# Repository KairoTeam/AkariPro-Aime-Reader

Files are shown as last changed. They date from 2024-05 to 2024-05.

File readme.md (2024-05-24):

# Akari Pro
使用 RP2040 + PN532 制作的适用于SEGA/KONAMI Aime 兼容读卡器，KairoTech闲鱼出售商品（现已经被Akari II替代）  

由于剩余大量物料，加群645758744可以付邮送一些~


- 支持卡片类型: [FeliCa](https://zh.wikipedia.org/wiki/FeliCa)（Amusement IC、Suica、八达通等）和 [MIFARE](https://zh.wikipedia.org/wiki/MIFARE)（Aime，Banapassport）
- 固件基于Mahuyo大佬的[Arduino-Aime-Reader](https://github.com/Sucareto/Arduino-Aime-Reader/blob/main/README.md)，十分感谢大佬Orz

固件相关信息和使用方法请查看Mahuyo大佬的[Arduino-Aime-Reader](https://github.com/Sucareto/Arduino-Aime-Reader/blob/main/README.md)，本项目仅修改了引脚定义以及适配RP2040

- 如果读卡器没有正常工作且游戏有使用 amdaemon 的，可以参考 config_common.json 内 aime > unit > port 确认端口号

### 使用教程
1. 焊接好PCB（废话）
2. 如果是新的RP2040可以直接插入，否则短接PCB上的flash的左边第一脚和最后一脚的同时接入USB线缆，在打开的新磁盘内放入AkariPro_1.00_202312111729.uf2
3. 测试完成后将PCB放入3D外壳并装好螺丝
4. 定位好磁铁后使用胶水将磁铁粘在顶板上（需要注意的是，部分胶水会对UV印刷层产生影响，我们使用的是百得的胶水）
5. 等待胶水硬化之后就可以测试一下能否正常安装，磁铁的定位请十分注意
6. 大功告成~

### 物料清单
- PCB元件: 在Repo的PCB文件夹内，但需要注意RP2040很挑Flash，淘宝里不到1RMB的基本无法使用，推荐买正规的Flash
- PCB制造 & 3D打印: 推荐嘉立创，3D请注意使用光固化
- 亚克力面板: 淘宝随便找，一般差距不会太大，使用UV印刷
- 螺母: 淘宝固万基旗舰店的[镀镍十字扁平头螺丝](https://m.tb.cn/h.g1rzLvyOX09U4BH?tk=sZ6CWHJcB1r)（自行购买请一定注意能否被磁铁吸住）
- 螺丝: 淘宝固万基旗舰店的[内六角夹板螺母](https://m.tb.cn/h.g1apAKJ12Nif9Q6?tk=VZhZWHJ1jPt MF7997)
- 磁铁: 淘宝鑫涌泉磁业[小圆形磁铁](https://m.tb.cn/h.gYnSHoJE2Vr6VK5?tk=gqvIWHJ1VeJ)

### 图片
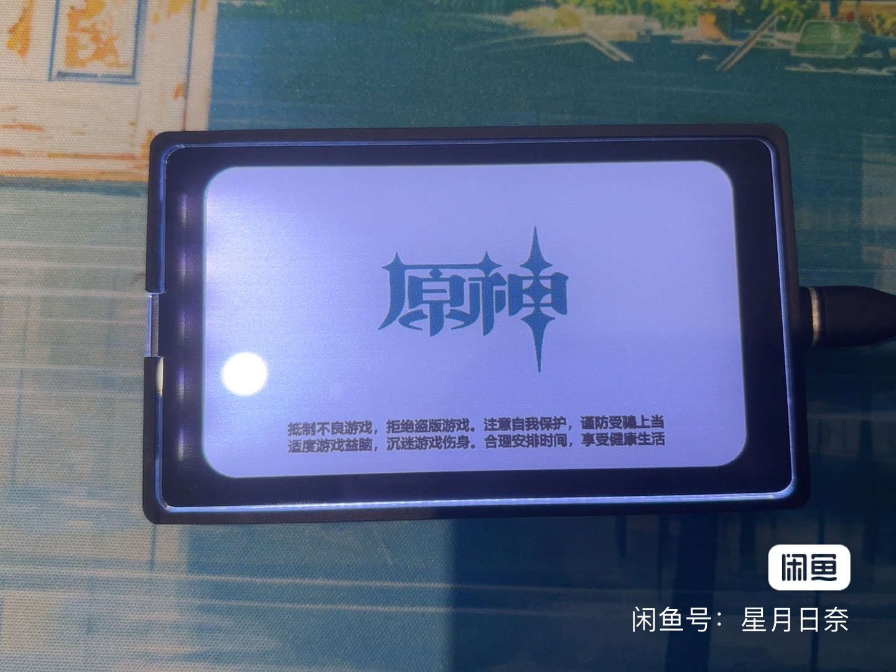
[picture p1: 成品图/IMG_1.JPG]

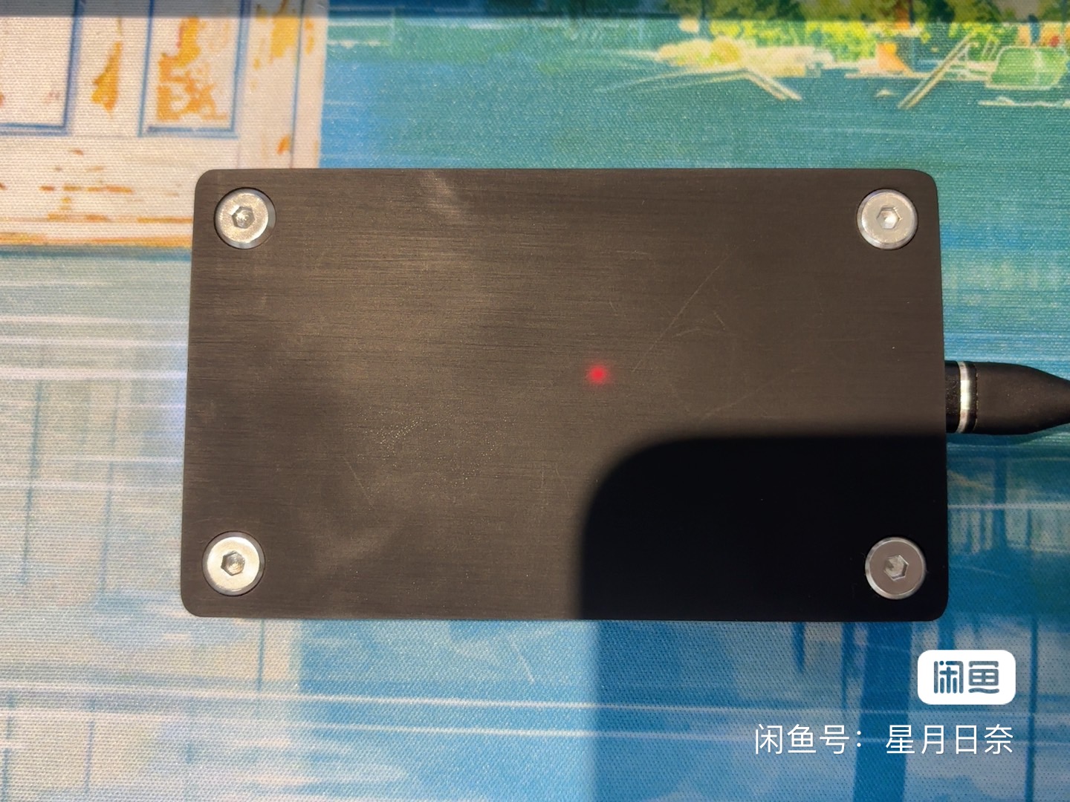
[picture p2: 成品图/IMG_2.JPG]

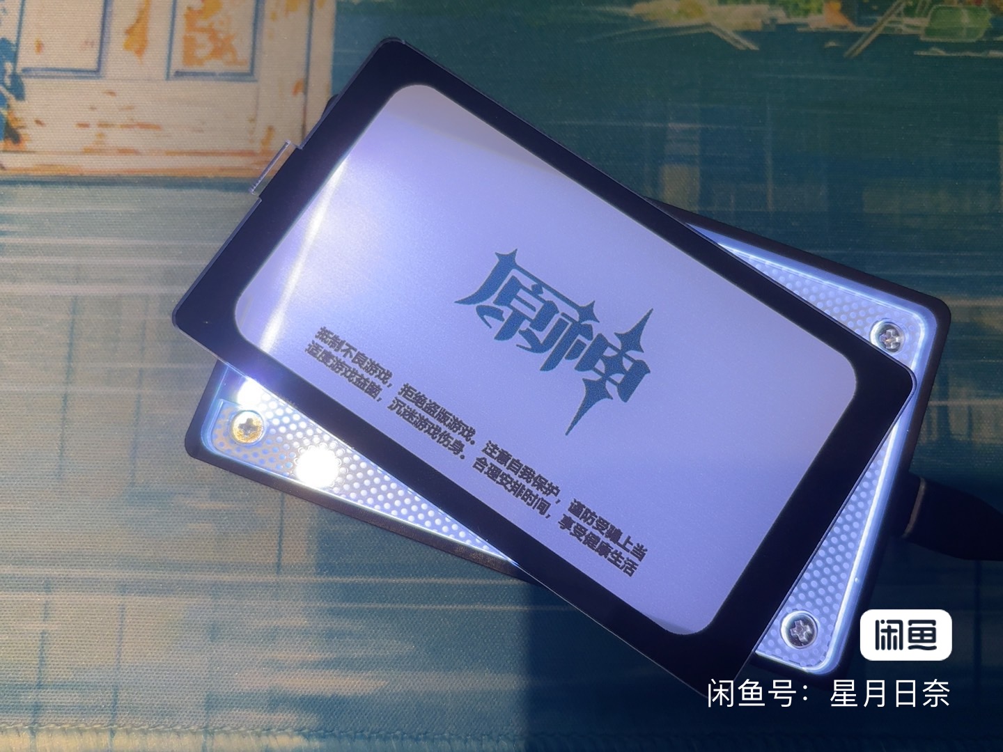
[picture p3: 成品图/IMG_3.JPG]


### 引用库：
- 固件: [Arduino-Aime-Reader](https://github.com/Sucareto/Arduino-Aime-Reader/blob/main/README.md)
- 驱动 WS2812B: [FastLED](https://github.com/FastLED/FastLED)
- 驱动 PN532: [PN532](https://github.com/elechouse/PN532) 或 [Aime_Reader_PN532](https://github.com/Sucareto/Aime_Reader_PN532)
- 读取 FeliCa 参考: [PN532を使ってArduinoでFeliCa学生証を読む方法](https://qiita.com/gpioblink/items/91597a5275862f7ffb3c)
- 读取 FeliCa 数据的程序: [NFC TagInfo](https://play.google.com/store/apps/details?id=at.mroland.android.apps.nfctaginfo)，[NFC TagInfo by NXP](https://play.google.com/store/apps/details?id=com.nxp.taginfolite)
- MIFARE 读写卡，数据分析: [MifareClassicTool](https://github.com/ikarus23/MifareClassicTool)，[MifareOneTool](https://github.com/xcicode/MifareOneTool)

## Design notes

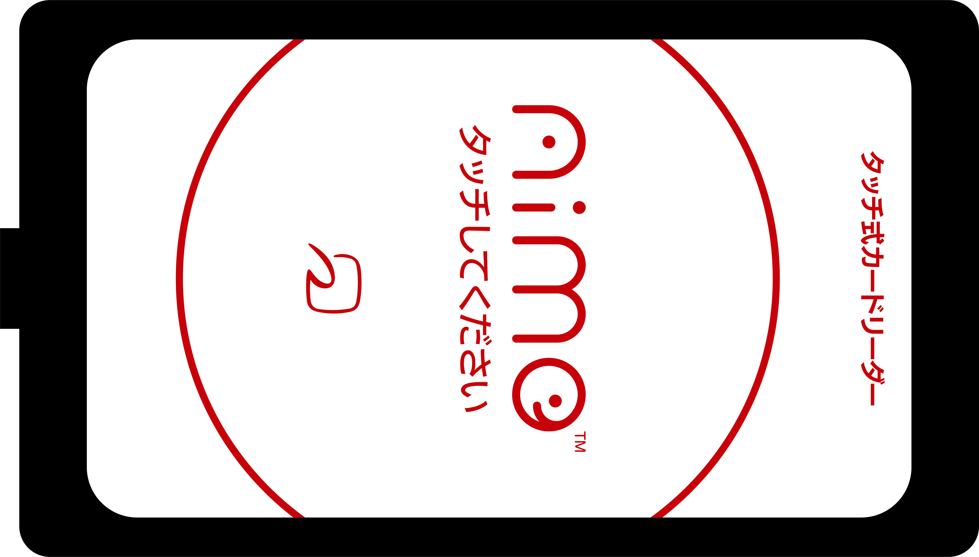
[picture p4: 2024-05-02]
面板/AIME_竖.png

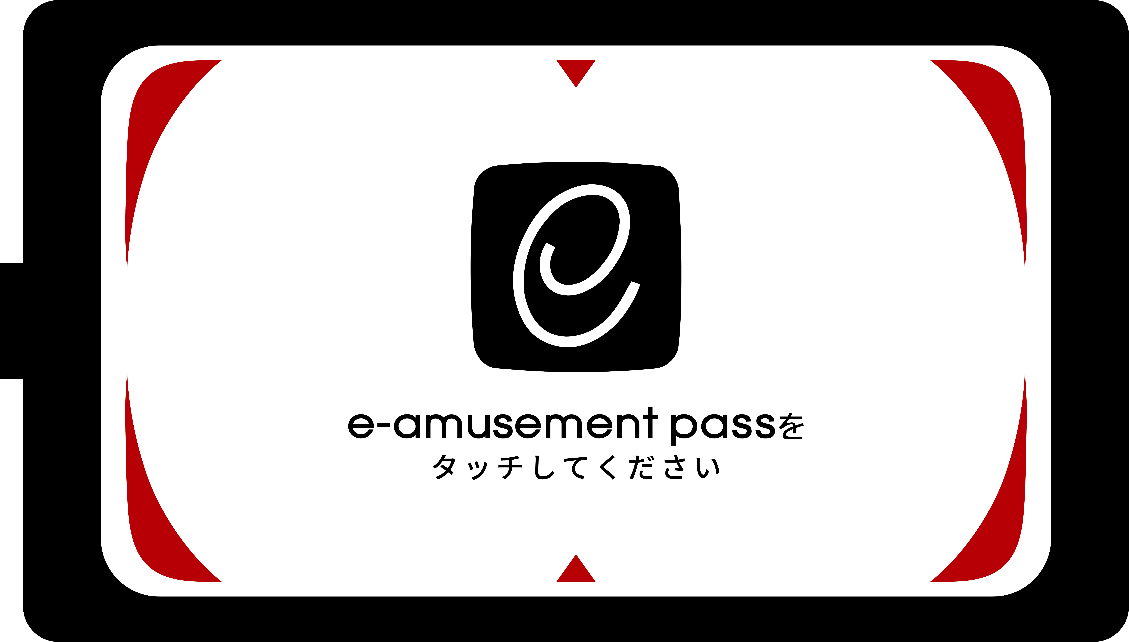
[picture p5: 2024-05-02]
面板/KONAMI_横.png

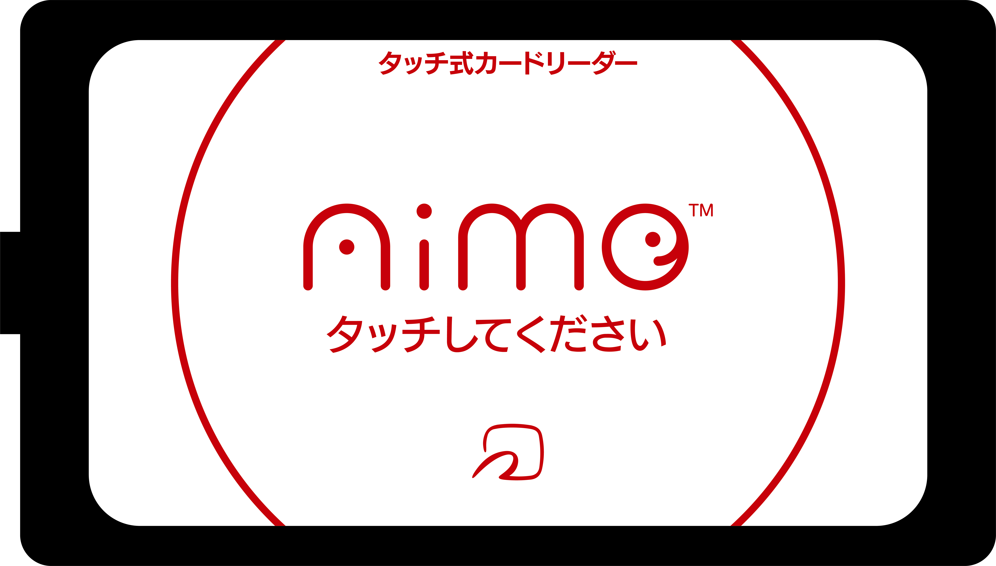
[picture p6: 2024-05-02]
面板/AIME_横.png

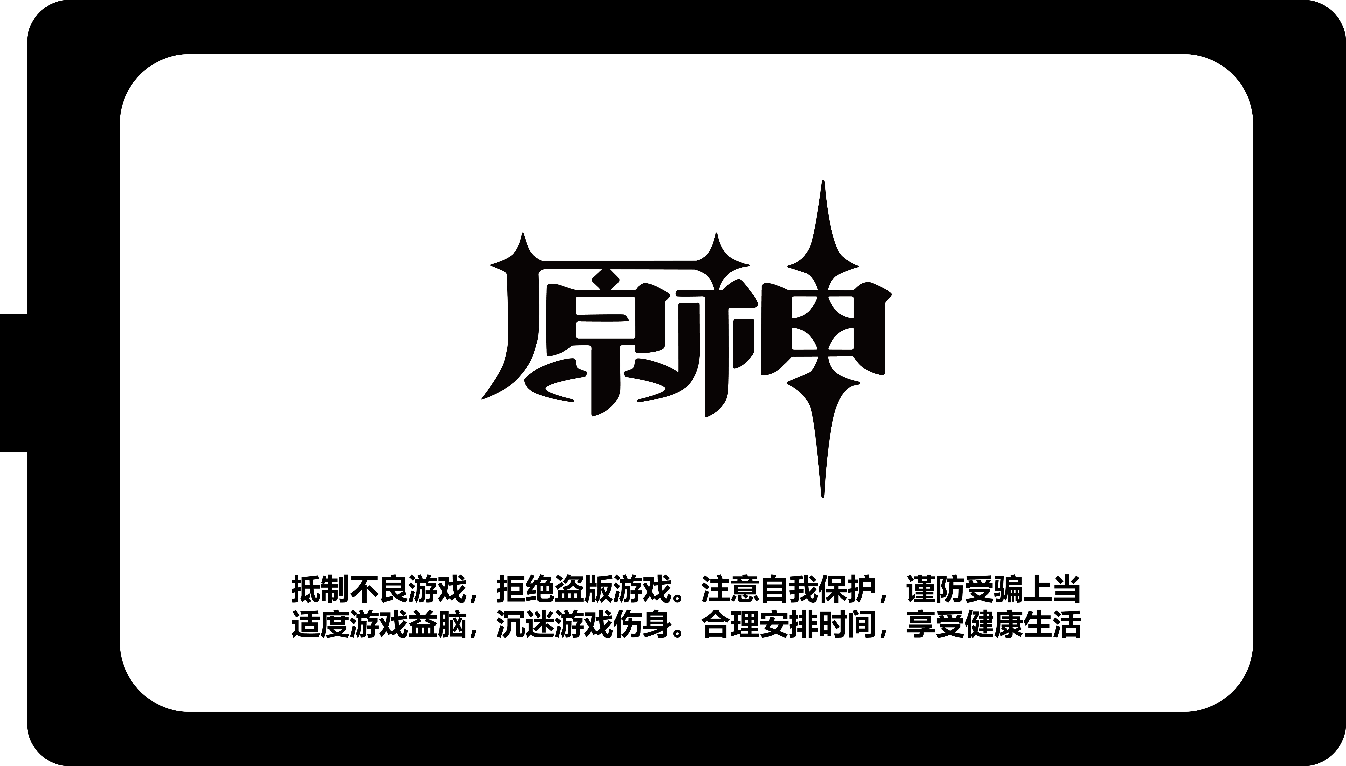
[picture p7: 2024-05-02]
面板/原神.png

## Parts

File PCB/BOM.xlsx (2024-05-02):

No. | Quantity | Comment | Designator | Footprint | Value | Manufacturer Part | Manufacturer | Supplier Part | Supplier
1 | 2 | 12pF | C1,C2 | C0603
2 | 8 | 100nF | C3,C4,C5,C6,C7,C8,C9,C10 | C0603
3 | 5 | WS2812B-4020 | LED1,LED2,LED3,LED4,LED5 | LED-SMD_WS2812B-4020 |  | WS2812B-4020 | worldsemi | C965557 | LCSC
4 | 1 | 1k | R1 | R0603
5 | 2 | 5.1k | R2,R3 | R0603
6 | 1 | RP2040 | U1 | LQFN-56_L7.0-W7.0-P0.4-EP |  | RP2040 | Raspberry Pi(树莓派) | C2040 | LCSC
7 | 1 | W25Q32JVSSIQ_C2834491 | U2 | SOIC-8_L5.2-W5.2-P1.27-LS7.9-BL |  | W25Q32JVSSIQ | WINBOND(华邦) | C2834491 | LCSC
8 | 1 | AMS1117-5.0_C347223 | U3 | SOT-223_L6.7-W3.5-P2.30-BR |  | AMS1117-5.0 | UMW(广东友台半导体) | C347223 | LCSC
9 | 1 | pn532 | U5 | PN532
10 | 1 | TYPE-610-1.6-T3 | USB | USB-C-SMD_TYPE-C-16P-610-1.6-T3 |  | TYPE-610-1.6-T3 | Yuandi(元迪) | C2972115 | LCSC
11 | 1 | 12MHz | X1 | CRYSTAL-SMD_4P-L2.5-W2.0-BL_XTAL12MHZ |  | ABM10AIG-12.000MHZ-4Z-T3 | ABRACON | C1985574 | LCSC

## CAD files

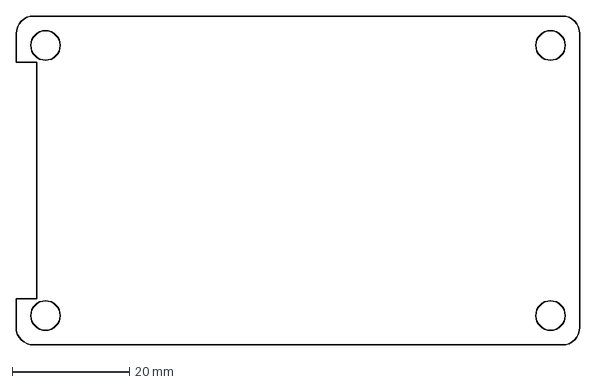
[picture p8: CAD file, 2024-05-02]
模型与导光板/导光板_2mm.dxf
96.0 x 56.0 mm

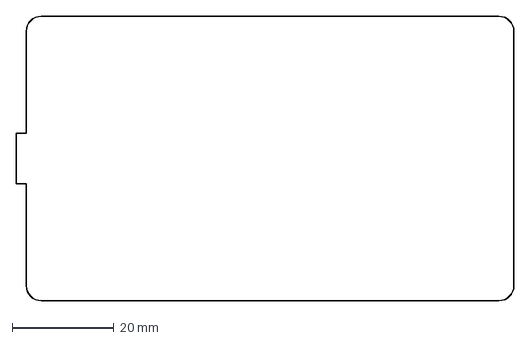
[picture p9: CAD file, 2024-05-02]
面板/面板切割文件.dxf
98.0 x 56.0 mm

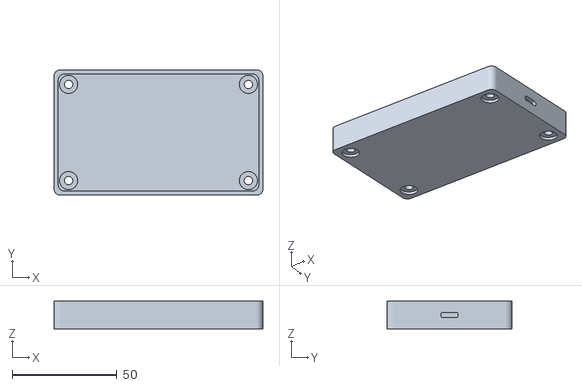
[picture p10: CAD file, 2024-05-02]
模型与导光板/主壳_1.01_202312161440.stl
100.0 x 60.0 x 13.2

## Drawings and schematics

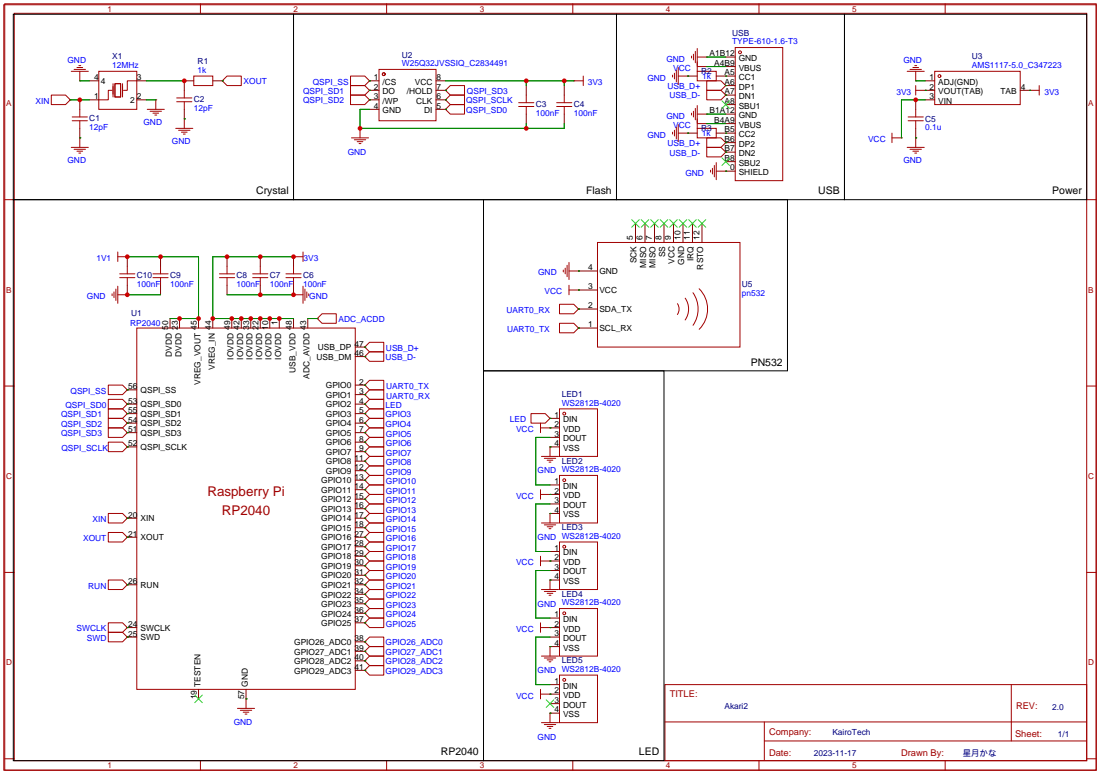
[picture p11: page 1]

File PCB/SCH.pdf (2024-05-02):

SBU2 B8 DN2 B7 DP2 B6 CC2 B5 VBUS B4A9 GND B1A12 SBU1 A8 DN1 A7 DP1 A6 CC1 A5 VBUS A4B9 GND A1B12
